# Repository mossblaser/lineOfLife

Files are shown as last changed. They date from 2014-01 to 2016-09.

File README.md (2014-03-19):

Line-of-Life
============

A glow-in-the-dark display for 1D cellular automata and other fun.

Python Library
--------------

A Python library is included for interfacing with the display. This can be
installed as follows:

	cd python/
	sudo python setup.py install

Example programs using this library are included in `python/examples/`.

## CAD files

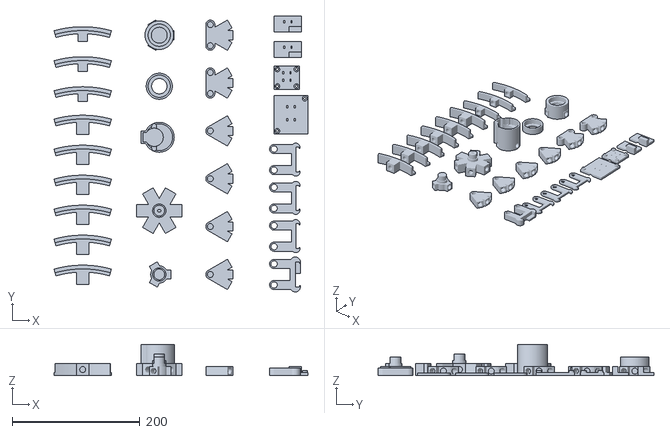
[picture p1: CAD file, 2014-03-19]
physical/all_components.stl
398.1 x 432.4 x 49.2

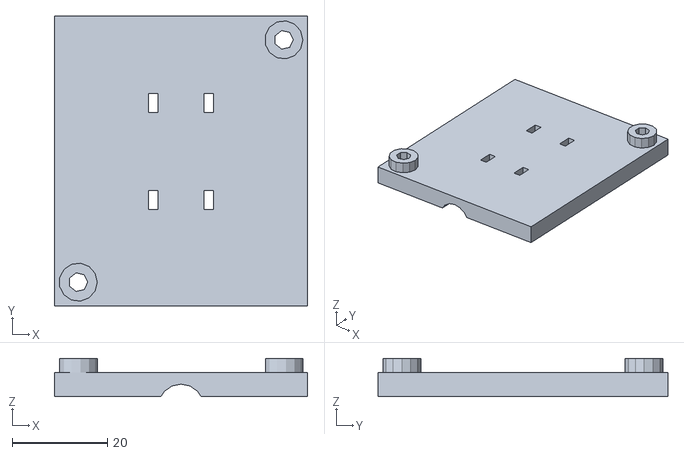
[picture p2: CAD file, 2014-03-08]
physical/arduino_holder.stl
53.1 x 60.8 x 8.00

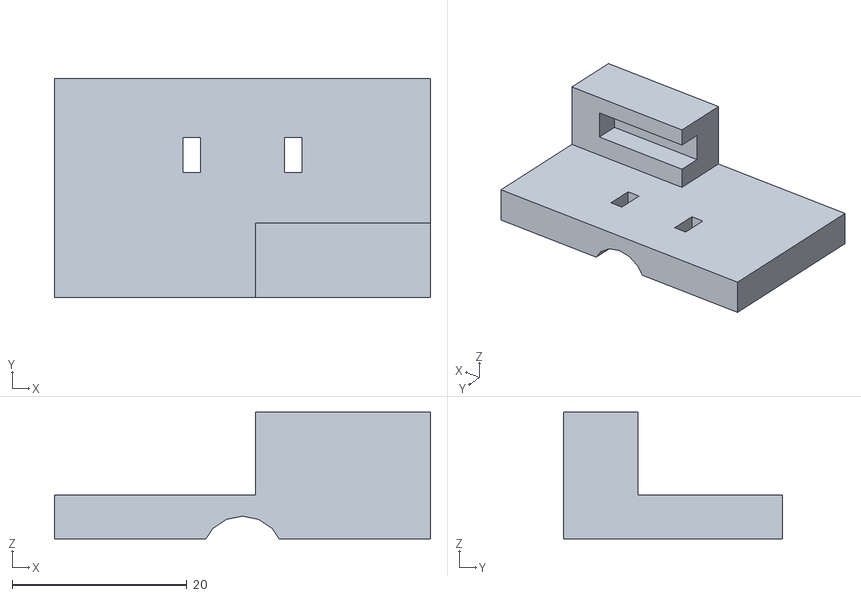
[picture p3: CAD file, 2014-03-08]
physical/junction_board_holder.stl
43.0 x 25.0 x 14.5

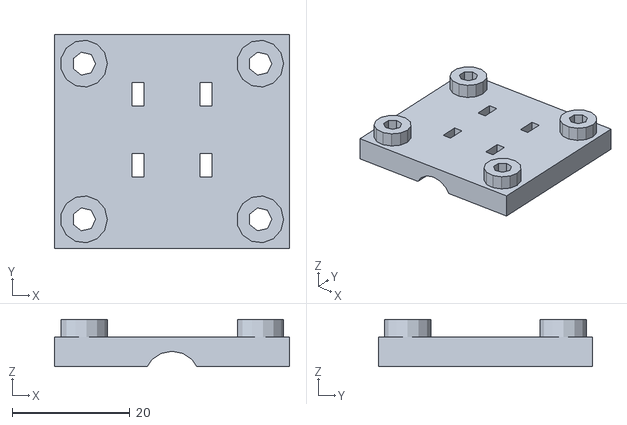
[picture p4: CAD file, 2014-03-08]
physical/motor_driver_holder.stl
40.0 x 36.5 x 8.00

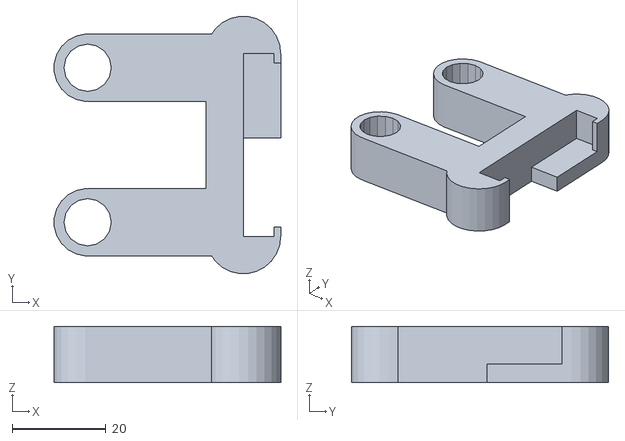
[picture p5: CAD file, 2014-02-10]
physical/led_holder.stl
48.4 x 54.9 x 12.0

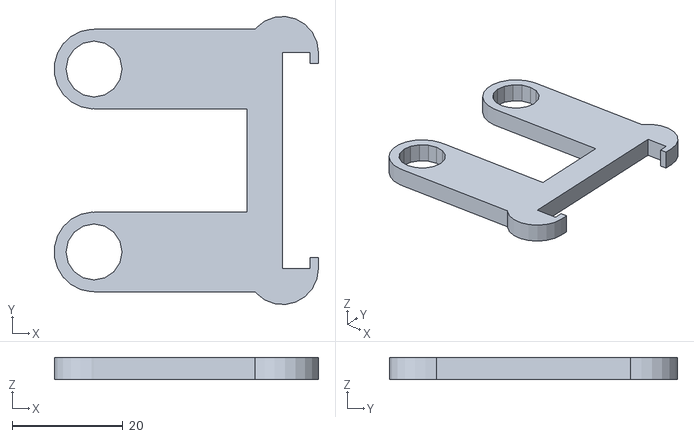
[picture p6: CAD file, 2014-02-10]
physical/led_grip.stl
47.6 x 52.0 x 4.00

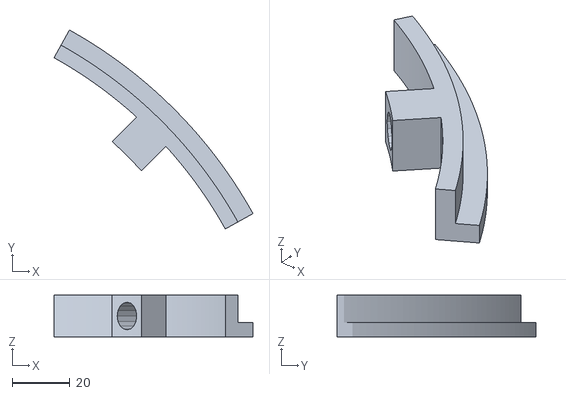
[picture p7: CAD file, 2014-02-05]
physical/top_display_grip.stl
69.0 x 69.0 x 14.4

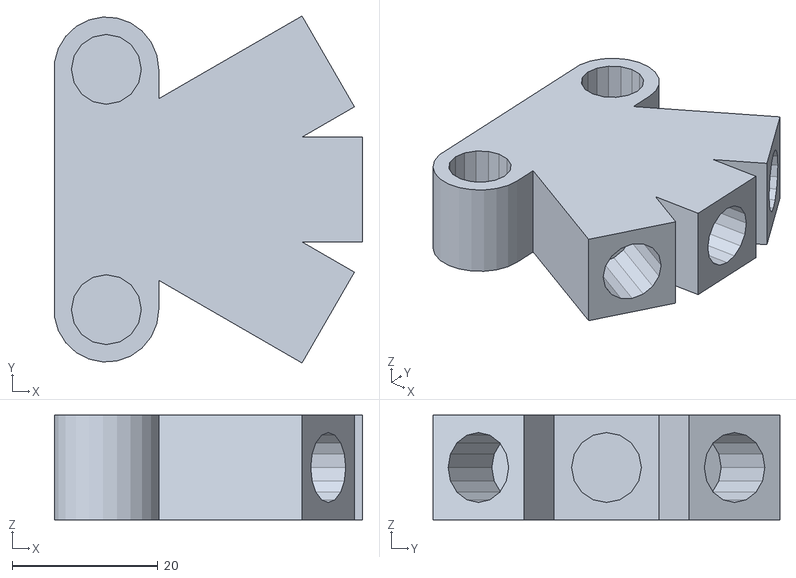
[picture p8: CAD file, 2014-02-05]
physical/double_bracket.stl
42.3 x 47.7 x 14.4

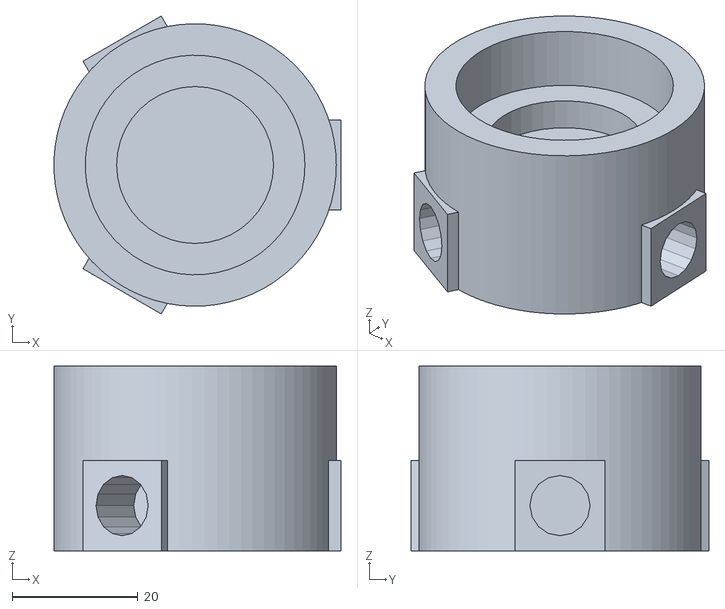
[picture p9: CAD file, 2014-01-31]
physical/top_bearing_grip.stl
45.7 x 47.5 x 29.4

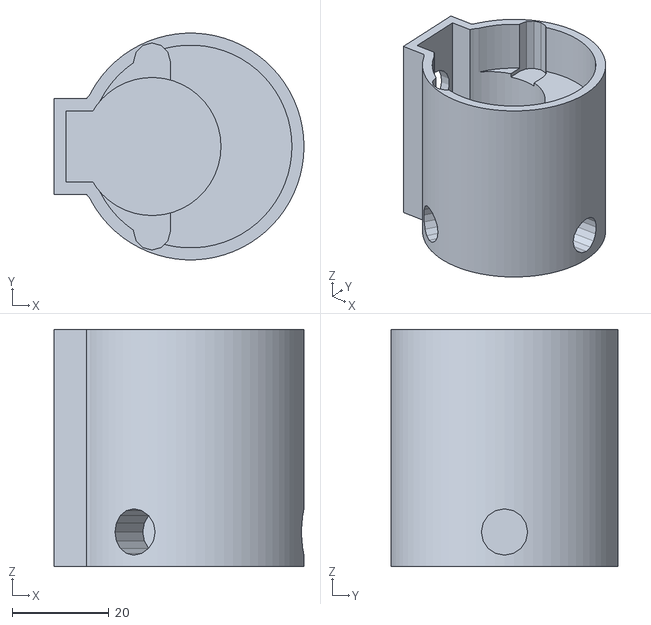
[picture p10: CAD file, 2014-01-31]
physical/motor_base.stl
51.8 x 47.0 x 49.2

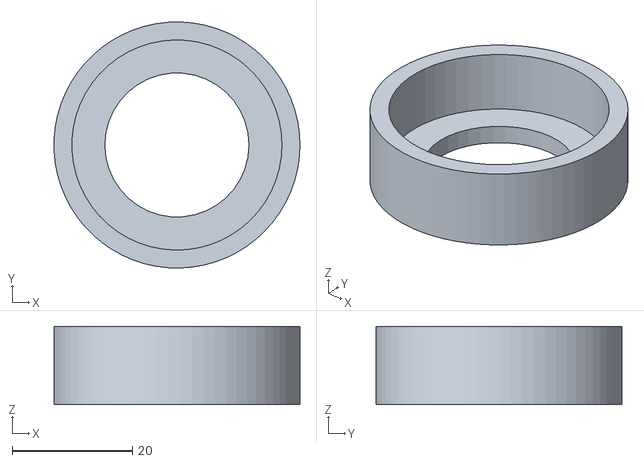
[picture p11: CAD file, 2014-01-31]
physical/motor_base_bearing_fitting.stl
41.0 x 41.0 x 13.0

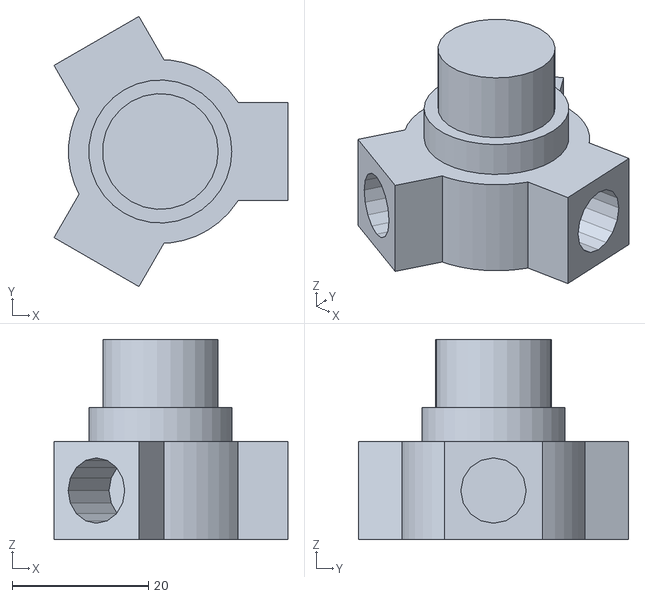
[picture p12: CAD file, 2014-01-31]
physical/top_axel.stl
34.4 x 39.7 x 29.4

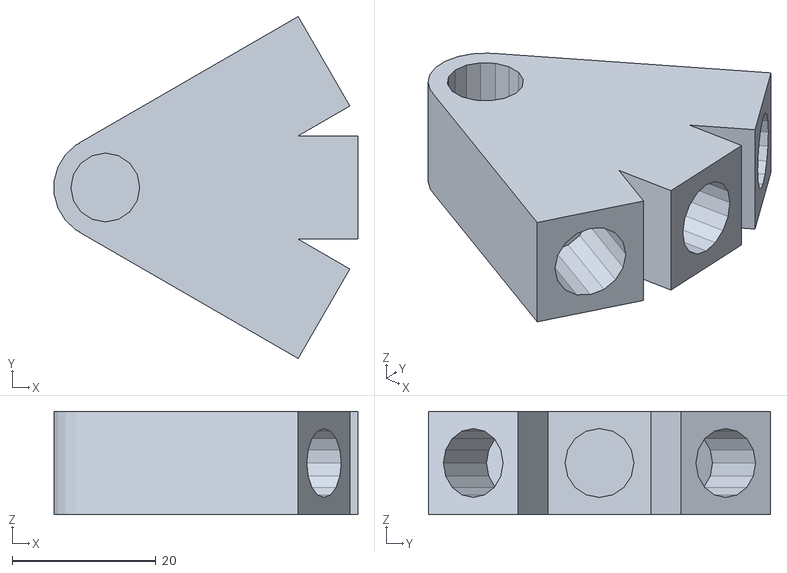
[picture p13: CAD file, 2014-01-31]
physical/bracket.stl
42.3 x 47.7 x 14.4

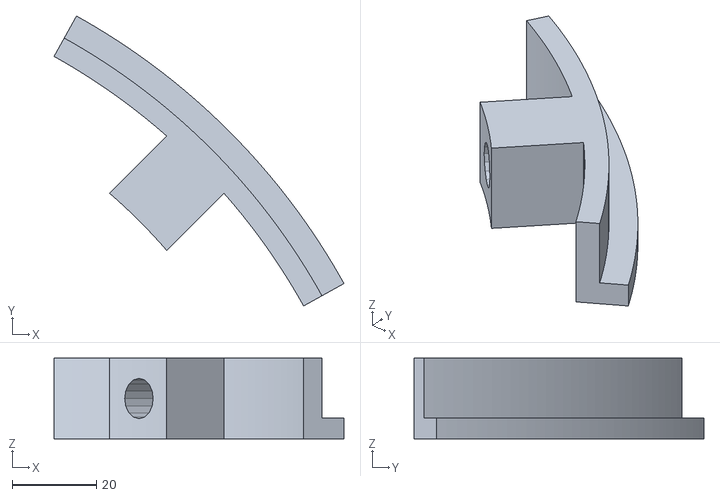
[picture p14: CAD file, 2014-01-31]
physical/base_display_grip.stl
69.0 x 69.0 x 19.2

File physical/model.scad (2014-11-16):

include <wedge.scad>;

// Minimum angle for fragmenting curves
$fa = 1;
//$fs = 0.5;

PI = 3.1415927;

////////////////////////////////////////////////////////////////////////////////
// Size Definitions
////////////////////////////////////////////////////////////////////////////////

// Size of the dowel rods used in construction
DOWEL_DIAMETER = 9;
DOWEL_RADIUS   = DOWEL_DIAMETER/2;

// Sizes of holes for dowel rods in various situations
DOWEL_PRINTED_SOCKET_RADIUS= DOWEL_RADIUS + 0.3;
DOWEL_CUT_HOLE_RADIUS= DOWEL_RADIUS * 3;

// Thickness of a block into which a dowel rod inserted should be
DOWEL_PRINTED_SOCKET_BLOCK = DOWEL_PRINTED_SOCKET_RADIUS * 3;
// Depth of a socket to accept the dowel rod
DOWEL_PRINTED_SOCKET_DEPTH = DOWEL_PRINTED_SOCKET_RADIUS * 2.5;

// As above but for load-bearing joints
DOWEL_PRINTED_SOCKET_BLOCK_LOADED = DOWEL_PRINTED_SOCKET_RADIUS * 4;
DOWEL_PRINTED_SOCKET_DEPTH_LOADED = DOWEL_PRINTED_SOCKET_RADIUS * 4;

// Maximum 3D printable size
MAX_3D_PRINT_DIMENSION = 90;

// Size of the glow-in-the-dark cylinder
DISPLAY_HEIGHT       = 609.6; // 24in
DISPLAY_CIRCUMFRENCE = 1000;  // 1m
DISPLAY_RADIUS       = (DISPLAY_CIRCUMFRENCE / PI) / 2;
DISPLAY_THICKNESS    = 1;


// The cardboard rings which live inside the display to hold its shape
DISPLAY_SHAPE_RING_THICKNESS = 3;  // Cardboard Thickness
DISPLAY_SHAPE_RINGS_START    = 50; // The offset from the bottom of the cylinder of the first ring.
DISPLAY_SHAPE_RINGS_END      = 50; // The offset from the top of the cylinder of the last ring.
DISPLAY_SHAPE_RINGS_NUM      = 3;  // Number of shaping rings

// Size of the ledge on each of the spokes which the display will rest.
DISPLAY_GRIP_LEDGE = 5;
// Thickness of the ledge on which the display sits
DISPLAY_GRIP_THICKNESS = 5;

// Bearing dimensions
BEARING_INNER_RADIUS = 18/2; // Inner radius
BEARING_OUTER_RADIUS = 34/2; // Outer radius
BEARING_THICKNESS    = 10;   // Ring thickness
BEARING_INNER_LIP    = 2;    // Size of the edge of the inner ring
BEARING_OUTER_LIP    = 5;    // Size of the fixed outer ring
BEARING_PRINT_SLACK  = 0.5;  // Amount of slack to add to the radius for 3D printed fittings

// Motor shaft dimensions
MOTOR_SHAFT_RADIUS        = (5+0.5)/2;
MOTOR_SHAFT_KEY_WIDTH     = 3+0.5;
MOTOR_SHAFT_LENGTH        = 6+1;
MOTOR_SHAFT_CENTER_OFFSET = 8;

// Motor Body Dimensions
MOTOR_RADIUS = 28/2 + 0.3;
MOTOR_BLOCK_RADIUS = 17.5 + 0.3;
MOTOR_BLOCK_WIDTH = 14.5 + 0.3;
MOTOR_DEPTH = 19 + 0.3;
MOTOR_TAB_RADIUS = 7/2 + 0.3;
MOTOR_TAB_SPACING = 35 + 0.3;
MOTOR_TAB_THICKNESS = 1;
MOTOR_WIRE_WIDTH = 12;
MOTOR_WIRE_HEIGHT = 15;

// Motor holder wall thicknesses
MOTOR_WALL_THICKNESS = 2.5;
// The thickness of the motor bearing cup's base
MOTOR_SHELF_THICKNESS = 3;
// The thickness of the outer ring around the base bearing
MOTOR_SHELF_RING_THICKNESS = 4;
// Slack added to the shelf's dimensions itself 
MOTOR_SHELF_SLACK = 0.5;

// Number of spokes/grips used to support the display
DISPLAY_BASE_SPOKES = 6;
// Number of spokes at the top of the display
DISPLAY_TOP_SPOKES = 3;

// Seperation between the two rods which run down the side of the system
// attached to the electronics.
DOUBLE_SHAFT_SEP = 33; // Approximately the width of circuit board (1.4")


// Parameters for the LED board holder
LED_GRIP_THICKNESS   = 4;
LED_HOLDER_THICKNESS = DOWEL_PRINTED_SOCKET_BLOCK;
LED_ARM_THICKNESS = 2.5; // Thickness of the fingers at the end of the arm
LED_ARM_OVERHANG = 2;//

// Distance of the LED boards from the dowel rod centers
LED_DISTANCE = 36;

LED_BOARD_THICKNESS = 4.0;
LED_WIDE_BOARD_THICKNESS = 5.5;
LED_SUPPORT_WIDTH = 18;
LED_BOARD_WIDTH = 39;

// Thickness of the panels holding circuit boards
CIRCUIT_HOLDER_THICKNESS = 5;

// Size of cable-ties
CABLE_TIE_THICKNESS = 2.0;
CABLE_TIE_WIDTH = 4.0;

// Screws and standoffs
SCREW_RADIUS = 2;
STANDOFF_RADIUS = 4;
STANDOFF_HEIGHT = 3;

// Clamp thickness for board holders
CLAMP_THICKNESS = 2.5;


////////////////////////////////////////////////////////////////////////////////
// Colour Palette
////////////////////////////////////////////////////////////////////////////////

COLOUR_CARDBOARD    = [184/255,165/255,103/255];
COLOUR_GLOW_IN_DARK = [198/255,245/255,188/255];
COLOUR_3D_PRINTED   = [0.2,0.2,0.2];


////////////////////////////////////////////////////////////////////////////////
// Components
////////////////////////////////////////////////////////////////////////////////

// The display cylinder and axel
module display() {
	// The display surface itself
	%color(COLOUR_GLOW_IN_DARK)
		difference() {
			cylinder(h = DISPLAY_HEIGHT, r=DISPLAY_RADIUS);
			translate([0,0,-0.5])
			cylinder(h = DISPLAY_HEIGHT+1, r=DISPLAY_RADIUS - DISPLAY_THICKNESS);
		}
	
	// The cardboard support rings 
	color(COLOUR_CARDBOARD)
		for (i = [0 : DISPLAY_SHAPE_RINGS_NUM-1]) {
			translate([0,0,DISPLAY_SHAPE_RINGS_START
			                 + i * (( DISPLAY_HEIGHT
			                          - DISPLAY_SHAPE_RINGS_START
			                          - DISPLAY_SHAPE_RINGS_END
			                        ) / (DISPLAY_SHAPE_RINGS_NUM-1))
			          ])
				difference() {
					// The ring
					cylinder( h = DISPLAY_SHAPE_RING_THICKNESS
					        , r = DISPLAY_RADIUS - DISPLAY_THICKNESS
					        );
					// Space for the axel
					translate([0,0,-0.5])
					cylinder( h = DISPLAY_SHAPE_RING_THICKNESS+1
					        , r = DOWEL_CUT_HOLE_RADIUS
					        );
				}
		}
}


// A part which sits on the end of a spoke and grips the display
module display_grip( angle
                   , DOWEL_PRINTED_SOCKET_BLOCK = DOWEL_PRINTED_SOCKET_BLOCK
                   , DOWEL_PRINTED_SOCKET_DEPTH = DOWEL_PRINTED_SOCKET_DEPTH
                   ) {
	// A wedge the width of the ledge which should be as big as can be 3D
	// printed (cosine rule)
	wedge_angle = acos( (2*pow(DISPLAY_RADIUS+DISPLAY_GRIP_LEDGE,2) - pow(MAX_3D_PRINT_DIMENSION,2))
	                    / (2*pow(DISPLAY_RADIUS+DISPLAY_GRIP_LEDGE,2))
	                  );
	
	echo("Difference of axel radius from display radius: ", DISPLAY_THICKNESS + DISPLAY_GRIP_THICKNESS);
	
	color(COLOUR_3D_PRINTED)
	rotate([0,0, angle]) {
		difference() {
			// The wedge with a lip
			intersection() {
				// The profile of the ledge
				union() {
					// The spoke accepting part
					cylinder( h = DOWEL_PRINTED_SOCKET_BLOCK
					        , r = DISPLAY_RADIUS - DISPLAY_THICKNESS
					        );
					// The ledge
					cylinder( h = DISPLAY_GRIP_THICKNESS
					        , r = DISPLAY_RADIUS + DISPLAY_GRIP_LEDGE
					        );
				}
				rotate([0,0, -wedge_angle/2])
					wedge( h = DOWEL_PRINTED_SOCKET_BLOCK
					     , r = DISPLAY_RADIUS + DISPLAY_GRIP_LEDGE
					     , d = wedge_angle
					     );
			}
			
			// The excess wedge excluding space for the axel
			difference() {
				translate([0,0,-0.5])
				cylinder( h = DOWEL_PRINTED_SOCKET_BLOCK + 1
				        , r = DISPLAY_RADIUS - DISPLAY_THICKNESS - DISPLAY_GRIP_THICKNESS
				        );
				translate([0, -DOWEL_PRINTED_SOCKET_BLOCK/2, 0])
					cube([ DISPLAY_RADIUS - DISPLAY_THICKNESS
					     , DOWEL_PRINTED_SOCKET_BLOCK
					     , DOWEL_PRINTED_SOCKET_BLOCK
					     ]);
			}
			
			// The excess axel socket 
			translate([0,0,-0.5])
			cylinder( h = DOWEL_PRINTED_SOCKET_BLOCK + 1
			        , r = DISPLAY_RADIUS
			              - DISPLAY_THICKNESS
			              - DISPLAY_GRIP_THICKNESS
			              - DOWEL_PRINTED_SOCKET_DEPTH
			        );
			
			// Drill out the hole for the dowel
			translate([0, 0, DOWEL_PRINTED_SOCKET_BLOCK/2])
				rotate([0, 90, 0])
					cylinder( h = DISPLAY_RADIUS - DISPLAY_THICKNESS - DISPLAY_GRIP_THICKNESS
					        , r = DOWEL_PRINTED_SOCKET_RADIUS
					        );
		}
	}
}
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

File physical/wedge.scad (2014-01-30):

//Title: Wedge Module
//Author: Alex English - ProtoParadigm
//Date: 1/4/2013
//License: Creative Commons - Share Alike - Attribution

//Usage: Include in your other .scad projects and call wedge with arguments for the height of the wedge, the radius of the wedge, and the angle of the wedge in degrees.  The resulting wedge will be placed with the point at the origin, extending into the z axis, with the angle starting at the x axis and extending counter-clockwise as per the right-hand rule.

//Updated: 1/12/2013 - Increased dimensions of wedge to be revoved when angle is more than 180 as per suggestion from kitwallace.

module wedge_180(h, r, d)
{
	rotate(d) difference()
	{
		rotate(180-d) difference()
		{
			cylinder(h = h, r = r);
			translate([-(r+1), 0, -1]) cube([r*2+2, r+1, h+2]);
		}
		translate([-(r+1), 0, -1]) cube([r*2+2, r+1, h+2]);
	}
}

module wedge(h, r, d)
{
	if(d <= 180)
		wedge_180(h, r, d);
	else
		rotate(d) difference()
		{
			cylinder(h = h, r = r);
			translate([0, 0, -1]) wedge_180(h+2, r+1, 360-d);
		}
}

//Example: wedge(10, 20, 145); //would create a wedge 10 high, with a radius of 20, and an angle of 33 degrees.

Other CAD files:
physical/base_axel.stl

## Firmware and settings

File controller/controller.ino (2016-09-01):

/**
 * Controller for the Line of Life display.
 */

#include <limits.h>

#include <SPI.h>

#include "TimerOne.h"

#include "controller.h"


////////////////////////////////////////////////////////////////////////////////
// Stepper Motor Driver
////////////////////////////////////////////////////////////////////////////////

// Accumulated number of steps taken.
static volatile unsigned char num_steps;

// Current stepper motor state
static int cur_motor_state = 0;


static void
on_timer_interrupt(void)
{
	// Step the motor
	if (STEPPER_CLOCKWISE) {
		for (int i = 0; i < 4; i++)
			digitalWrite(MOTOR_PINS[4-i-1], (MOTOR_STATES[cur_motor_state] & 1<<i)!=0);
	} else {
		for (int i = 0; i < 4; i++)
			digitalWrite(MOTOR_PINS[i], (MOTOR_STATES[cur_motor_state] & 1<<i)!=0);
	}
	
	num_steps++;
	
	// Advance stepper state
	cur_motor_state ++;
	if (cur_motor_state >= NUM_MOTOR_STATES)
		cur_motor_state = 0;
}


void
motor_setup(void)
{
	// Set up pins
	for (int i = 0; i < 4; i++) {
		pinMode(MOTOR_PINS[i], OUTPUT);
		digitalWrite(MOTOR_PINS[i], LOW);
	}
	
	Timer1.initialize(STEP_MICROSECONDS);
	Timer1.attachInterrupt(on_timer_interrupt);
}

////////////////////////////////////////////////////////////////////////////////
// Automata rendering (for when the host is not sending anything...)
////////////////////////////////////////////////////////////////////////////////

#ifdef SHOW_AUTOMATA

// The bitmap of the text to display before showing each rule is displayed
static unsigned char presenting_msg[][NUM_VERTICAL_BYTES] = {
#include "presenting_bitmap.h"
};
#define PRESENTING_MSG_LENGTH (sizeof(presenting_msg) / sizeof(unsigned char[NUM_VERTICAL_BYTES]))

// The bitmaps of the numbers
static unsigned char numbers[10][PRESENTING_MSG_LENGTH] = {
#include "number_bitmaps.h"
};

typedef enum {
	// Pick a rule to demonstrate and output a blank line to seperate off the
	// previous image.
	AUTOMATA_MODE_PICK_RULE,
	
	// Output some text stating which rule is about to be shown
	AUTOMATA_MODE_TEXT,
	
	// Generate and display an initial state for the automaton
	AUTOMATA_MODE_INITIAL_STATE,
	
	// Run the cellular automaton and output the current state (for a while).
	AUTOMATA_MODE_RUN,
} automata_mode_t;

/**
 * Returns a pointer to a line of display graphics to show which (over time)
 * illustrates the operation of a 1D cellular automata. Call once per line.
 */
unsigned char *get_automata_frame() {
	static automata_mode_t mode = AUTOMATA_MODE_PICK_RULE;
	
	// The current rule to use
	static int rule = 0;
	
	// The current frame number for this automaton
	static int frame = AUTOMATA_FRAMES;
	
	// Buffers holding the current state and a second buffer to write the new
	// state into. Flipped after each update. Though in principle only one buffer
	// is needed, having two a: simplifies life a little but mostly b: means we
	// can check if the automata actually does anything!
	static unsigned char buf_a[NUM_VERTICAL_BYTES] = {1};
	static unsigned char buf_b[NUM_VERTICAL_BYTES] = {1};
	static unsigned char *cur_state = buf_a;
	static unsigned char *next_state = buf_b;
	
	switch (mode) {
		
		case AUTOMATA_MODE_PICK_RULE:
			// Pick a new rule. With a 75% chance, pick a known good one
			if (random(4) == 0) {
				rule = random(0x00, 0xFF + 1);
			} else {
				int good_rules[] = AUTOMATA_KNOWN_GOOD_RULES;
				rule = good_rules[random(sizeof(good_rules) / sizeof(good_rules[0]))];
			}
			
			mode = AUTOMATA_MODE_TEXT;
			frame = 0;
			
			// Display a blank line
			for (int byte_num = 0; byte_num < NUM_VERTICAL_BYTES; byte_num++)
				cur_state[byte_num] = 0;
			return cur_state;
		
		case AUTOMATA_MODE_TEXT:
			// The fixed text
			for (int byte_num = 0; byte_num < NUM_VERTICAL_BYTES; byte_num++)
				cur_state[byte_num] = presenting_msg[frame][byte_num];
			
			// Add the rule number to the text
			{
				int offset = NUM_VERTICAL_BYTES - 3;
				int hundreds = rule / 100;
				int tens = (rule - (hundreds * 100)) / 10;
				int units = rule - (hundreds * 100) - (tens * 10);
				if (hundreds)
					cur_state[offset++] = numbers[hundreds][frame];
				if (hundreds || tens)
					cur_state[offset++] = numbers[tens][frame];
				cur_state[offset++] = numbers[units][frame];
			}
			
			frame++;
			if (frame >= PRESENTING_MSG_LENGTH) {
				mode = AUTOMATA_MODE_INITIAL_STATE;
				frame = 0;
			}
			
			return cur_state;
		
		case AUTOMATA_MODE_INITIAL_STATE:
			// Chose a starting state (either random or a single pixel)
			if (random(2) == 0) {
				// Random
				for (int byte_num = 0; byte_num < NUM_VERTICAL_BYTES; byte_num++)
					cur_state[byte_num] = random(0x00, 0xFF + 1);
			} else {
				// Single pixel
				for (int byte_num = 0; byte_num < NUM_VERTICAL_BYTES; byte_num++)
					cur_state[byte_num] = 0;
				cur_state[NUM_VERTICAL_BYTES / 2] = 1<<4;
			}
			
			mode = AUTOMATA_MODE_RUN;
			frame = 0;
			
			return cur_state;
		
		case AUTOMATA_MODE_RUN:
			// Compute next automata state
			for (int bit_num = 0; bit_num < VERTICAL_PIXELS; bit_num++) {
				int cur_byte_num =  bit_num / 8;
				int cur_bit_index = bit_num % 8;
				int prev_byte_num =  (bit_num-1) / 8;
				int prev_bit_index = (bit_num-1) % 8;
				int next_byte_num =  (bit_num+1) / 8;
				int next_bit_index = (bit_num+1) % 8;
				
				unsigned char cur_byte = cur_state[cur_byte_num];
				unsigned char prev_byte = (prev_byte_num >= 0 &&
				                           prev_byte_num < NUM_VERTICAL_BYTES)
				                          ? cur_state[prev_byte_num]
				                          : 0;
				unsigned char next_byte = (next_byte_num >= 0 &&
				                           next_byte_num < NUM_VERTICAL_BYTES)
				                          ? cur_state[next_byte_num]
				                          : 0;
				
				bool cur_bit = (cur_byte >> cur_bit_index) & 1;
				bool prev_bit = (prev_byte >> prev_bit_index) & 1;
				bool next_bit = (next_byte >> next_bit_index) & 1;
				
				next_state[cur_byte_num] = (next_state[cur_byte_num] & ~(1<<cur_bit_index))
				                           | (((rule >> ((prev_bit << 0) +
				                                         (cur_bit  << 1) +
				                                         (next_bit << 2))) & 1) << cur_bit_index);
			}
			
			// Flip the two buffers
			{
				unsigned char *tmp = cur_state;
				cur_state = next_state;
				next_state = tmp;
			}
			
			// If the state hasn't meaningfully changed or we've run for long enough,
			// move on to the next state
			{
				frame++;
				
				bool changed = false;
				for (int byte_num = 0; byte_num < NUM_VERTICAL_BYTES; byte_num++)
					changed |= cur_state[byte_num] != next_state[byte_num];
				
				if ((frame > AUTOMATA_MIN_FRAMES && !changed) ||
				    frame >= AUTOMATA_FRAMES)
					mode = AUTOMATA_MODE_PICK_RULE;
			}
			
			return cur_state;
		
		default:
			mode = AUTOMATA_MODE_PICK_RULE;
			return cur_state;
	}
}

#endif

////////////////////////////////////////////////////////////////////////////////
// LED Driving
////////////////////////////////////////////////////////////////////////////////

// Display buffer (head==tail is empty)
unsigned char buf[DISPLAY_BUFFER_LENGTH][NUM_VERTICAL_BYTES];
unsigned int  buf_head=0u;
unsigned int  buf_tail=0u;

// Emergency buffer -- a bitmap to display if no pixels are sent
#ifndef SHOW_AUTOMATA
static unsigned char emg_buf[][NUM_VERTICAL_BYTES] = {
#include "error_bitmap.h"
};
#define EMG_BUF_LENGTH (sizeof(emg_buf) / sizeof(unsigned char[NUM_VERTICAL_BYTES]))
static unsigned int emg_buf_cursor = 0u;
#endif


// Current pixel width, in pixel fractions (default to square pixels)
unsigned int cur_pixel_width = PIXEL_FRACTION;
unsigned int next_pixel_width = PIXEL_FRACTION;

// The amount of the cur_pixel_width (in pixel fractions) the LEDs are on.
unsigned int cur_pixel_duty = PIXEL_FRACTION;
unsigned int next_pixel_duty = PIXEL_FRACTION;


/**
 * Immediately empty the LED line buffer
 */
void
led_buffer_clear()
{
	buf_head = buf_tail = 0;
}


/**
 * Find out if the LED output buffer is empty
 */
bool
is_led_buffer_empty()
{
	return buf_head == buf_tail;
}


/**
 * Set the width of the next pixel to be displayed.
 */
void
led_set_pixel_width(unsigned int pixel_width)
{
	unsigned int old_pixel_width = next_pixel_width;
	
	next_pixel_width = pixel_width;
	// Clamp value 
	if (next_pixel_width <= 0)
		next_pixel_width = 1u;
	
	// Scale the duty to match the new pixel width
	led_set_pixel_duty((next_pixel_width*led_get_pixel_duty()) / old_pixel_width);
}


/**
 * Get the width of the next pixel to be displayed.
 */
unsigned int
led_get_pixel_width(void)
{
	return next_pixel_width;
}


/**
 * Set the duty of the next pixel to be displayed.
 */
void
led_set_pixel_duty(unsigned int pixel_duty)
{
	next_pixel_duty = pixel_duty;
	// Clamp value
	if (next_pixel_duty <= 0)
		next_pixel_duty = 1u;
	else if (next_pixel_duty > led_get_pixel_width())
		next_pixel_duty = led_get_pixel_width();
}


/**
 * Get the duty of the next pixel to be displayed.
 */
unsigned int
led_get_pixel_duty(void)
{
	return next_pixel_duty;
}


/**
 * Insert an item into the buffer. Returns a pointer to the buffer entry which
 * has been allocated or NULL if the buffer is full.
 */
unsigned char *
led_buffer_insert(void)
{
	unsigned int old_tail = buf_tail;
	unsigned int new_tail = (old_tail+1)%DISPLAY_BUFFER_LENGTH;
	if (new_tail == buf_head) {
		// The buffer is full
		return NULL;
	} else {
		buf_tail = new_tail;
		return buf[old_tail];
	}
}


/**
 * Number of free spaces in the buffer.
 */
unsigned int
get_led_buffer_spaces()
{
	return (((int)buf_head - (int)buf_tail) + (int)DISPLAY_BUFFER_LENGTH - 1) % (int)DISPLAY_BUFFER_LENGTH;
}

/**
 * Refresh the LED display if needed
 */
void
led_loop() {
	// Control the duty-cycle of the display
	digitalWrite(nOE_PIN, !(num_steps < STEPS_PER_PIXEL_FRACTION(cur_pixel_duty)));
	
	// Does the display actually need to be refreshed?
	if (num_steps < STEPS_PER_PIXEL_FRACTION(cur_pixel_width))
		return;
	
	// Only maintain the period if the pixel width hasn't changed
	if (cur_pixel_width != next_pixel_width)
		num_steps = 0;
	else
		num_steps %= STEPS_PER_PIXEL_FRACTION(cur_pixel_width);
	
	// Update the pixel duty and width
	cur_pixel_width = next_pixel_width;
	cur_pixel_duty  = next_pixel_duty;
	
	// Work out what to display
	unsigned char *cur_buf;
	if (buf_head == buf_tail) {
#ifdef SHOW_AUTOMATA
		// Empty buffer, run the automata demo
		cur_buf = get_automata_frame();
#else
		// Empty buffer, show 'emergency' message
		cur_buf = &(emg_buf[emg_buf_cursor++][0]);
		if (emg_buf_cursor >= EMG_BUF_LENGTH)
			emg_buf_cursor = 0u;
#endif
	} else {
		// Consume item from buffer
		cur_buf = &(buf[buf_head++][0]);
		if (buf_head >= DISPLAY_BUFFER_LENGTH)
			buf_head = 0u;
		
		// Also reset the emergency buffer cursor so the emergency buffer starts
		// from scratch when it is next used.
		emg_buf_cursor = 0u;
	}
	
	// Refresh the display
	for (int i = NUM_VERTICAL_BYTES-1; i>=0; i--)
		SPI.transfer(cur_buf[i]);
	digitalWrite(LE_PIN, HIGH);
	digitalWrite(LE_PIN, LOW);
	
}


////////////////////////////////////////////////////////////////////////////////
// Command Interface
////////////////////////////////////////////////////////////////////////////////


/**
 * Command interface state-machine states.
 */
enum cmd_state {
	// The normal state while not running any particular command.
	CMD_STATE_IDLE,
	
	// Reading in a line of display values from the host
	CMD_STATE_READ_LINE,
	
	// Waiting for the display buffer to become non-full before confirming to the
	// host that this has occurred.
	CMD_STATE_WAIT_UNTIL_BUFFER_NOT_FULL,
	
	// Waiting for the display buffer to become flushed.
	CMD_STATE_FLUSH,
	
	// Waiting for a register's write data to arrive
	CMD_STATE_READ_REG_VALUE,
} cmd_state = CMD_STATE_IDLE;


/**
 * The register which will be written in the CMD_STATE_READ_REG_VALUE state.
 */
reg_t selected_register;


unsigned int
cmd_read_reg(reg_t reg)
{
	switch (reg) {
		case REG_DISPLAY_HEIGHT: return VERTICAL_PIXELS;           break;
		case REG_DISPLAY_WIDTH:  return HORIZONTAL_PIXELS;         break;
		case REG_RPM:            return (int)(DISPLAY_RPM*(1<<8)); break;
		
		case REG_PIXEL_ASPECT_RATIO:
			// Convert to fixed point 8.8
			return (led_get_pixel_width()<<8) / PIXEL_FRACTION;
		
		case REG_PIXEL_DUTY:
			// Convert to fixed point 8.8
			return (led_get_pixel_duty()<<8) / led_get_pixel_width();
		
		case REG_BUFFER_SIZE:
			return (DISPLAY_BUFFER_LENGTH-1)<<16 | get_led_buffer_spaces();
		
		default:
			// Return 0xDEAD for nonexistant registers
			return 0xDEADu;
	}
}

void
cmd_write_reg(reg_t reg, unsigned int value)
{
	switch (reg) {
		// Read-only registers
		default:
		case REG_DISPLAY_HEIGHT:
		case REG_DISPLAY_WIDTH:
		case REG_RPM:
		case REG_BUFFER_SIZE:
			break;
		
		case REG_PIXEL_ASPECT_RATIO:
			// Convert from fixed point 8.8
			led_set_pixel_width((PIXEL_FRACTION * value)>>8);
			break;
		
		case REG_PIXEL_DUTY:
			// Find number of pixel fractions in 8.8 and then convert to integer.
			led_set_pixel_duty((value * led_get_pixel_width())>>8);
			break;
	}
}


/**
 * Execute one iteration of the command evaluating state machine. This should be
 * interleaved with the LED driving state machine for propper operation.
 */
void
cmd_loop(void)
{
	switch (cmd_state) {
		case CMD_STATE_IDLE:
			// Try and read a command
			if (Serial.available()) {
				unsigned char cmd      = Serial.read();
				opcode_t opcode        = (opcode_t)(cmd & CMD_OPCODE_MASK);
				unsigned int immediate = cmd & CMD_IMMEDIATE_MASK;
				
				switch (opcode) {
					// Unrecognised commands are ignored
					default:
					case OPCODE_NO_OPERATION:
						return;
					
					case OPCODE_PUSH_LINE:
						cmd_state = CMD_STATE_READ_LINE;
						break;
					
					case OPCODE_FLUSH_BUFFER:
						cmd_state = CMD_STATE_FLUSH;
						break;
					
					case OPCODE_CLEAR_BUFFER:
						led_buffer_clear();
						break;
					
					case OPCODE_REG_READ:
						{
							unsigned int reg_value = cmd_read_reg((reg_t)immediate);
							Serial.write((unsigned char)(reg_value>>8u));
							Serial.write((unsigned char)(reg_value&0xFFu));
						}
						break;
					
					case OPCODE_REG_WRITE:
						cmd_state = CMD_STATE_READ_REG_VALUE;
						selected_register = (reg_t)immediate;
						break;
					
					case OPCODE_PING:
						Serial.write((unsigned char)(PROTOCOL_VERSION<<4u | ((unsigned char)immediate)));
						break;
				}
			}
			break;
		
		case CMD_STATE_READ_LINE:
			// Wait for a full line of input to arrive for the display
			if (Serial.available() >= NUM_VERTICAL_BYTES) {
				// Place the pixels in the buffer
				unsigned char *buffer = led_buffer_insert();
				if (buffer == NULL) {
					// Discard the data, for some reason we tried to over-fill the buffer
					for (int i = 0; i < NUM_VERTICAL_BYTES; i++)
						Serial.read();
				} else {
					for (int i = 0; i < NUM_VERTICAL_BYTES; i++)
						buffer[i] = Serial.read();
				}
				// Potentially block until the buffer has more space
				cmd_state = CMD_STATE_WAIT_UNTIL_BUFFER_NOT_FULL;
			}
			break;
		
		case CMD_STATE_WAIT_UNTIL_BUFFER_NOT_FULL:
			{
				// Allow the host to un-block the system by sending another command
				if (Serial.available()) {
					cmd_state = CMD_STATE_IDLE;
					break;
				}
				
				// Block until there are free spaces in the output buffer
				unsigned int free_spaces = get_led_buffer_spaces();
				if (free_spaces) {
					Serial.write(free_spaces);
					cmd_state = CMD_STATE_IDLE;
				}
			}
			break;
		
		case CMD_STATE_FLUSH:
			// Allow the host to un-block the system by sending another command
			if (Serial.available()) {
				cmd_state = CMD_STATE_IDLE;
				break;
			}
			
			// Block until the buffer is empty
			if (is_led_buffer_empty()) {
				Serial.write(0xFF);
				cmd_state = CMD_STATE_IDLE;
			}
			break;
		
		case CMD_STATE_READ_REG_VALUE:
			if (Serial.available() >= 2) {
				// Read the new value
				unsigned int value = Serial.read();
				value = (value<<8u) | Serial.read();
				
				// Write to the register
				cmd_write_reg(selected_register, value);
				cmd_state = CMD_STATE_IDLE;
			}
			break;
		
		default:
			cmd_state = CMD_STATE_IDLE;
	}
}


////////////////////////////////////////////////////////////////////////////////
// Main program
////////////////////////////////////////////////////////////////////////////////


void setup() {
	randomSeed(analogRead(5));
	
	Serial.begin(BAUD_RATE);
	
	SPI.begin();
	SPI.setBitOrder(MSBFIRST);
	SPI.setClockDivider(SPI_CLOCK_DIV16); // 16MHz/16 = 1MHz
	SPI.setDataMode(SPI_MODE0); // Posedge sensitive, Clock Idle Low
	
	motor_setup();
	
	pinMode(LE_PIN, OUTPUT);
	pinMode(nOE_PIN, OUTPUT);
	
	digitalWrite(LE_PIN, LOW);
	digitalWrite(nOE_PIN, LOW);
}


void loop() {
	led_loop();
	cmd_loop();
}

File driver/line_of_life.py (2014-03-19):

#!/usr/bin/env python

"""
An implementation of and library for the host interface to the Line of Life
controller.
"""

import random


class ProtocolError(Exception):
	"""
	Errors thrown by violations of the LineOfLife protocol.
	"""
	pass


class LineOfLife(object):
	"""
	A (blocking) interface to the Line of LIfe display hardware.
	"""
	
	
	def __init__(self, pipe):
		"""
		Connect to a line of life display at the end of the given pipe, for example
		a Serial connection.
		"""
		
		self.pipe = pipe
		
		# Cached display constants
		self._display_height = None
		self._display_width = None
		
		# Re-sync on first connection
		self.resync()
	
	
	def resync(self):
		"""
		Resynchronise with the controller putting it into the idle state.
		"""
		# Since all blocking commands are terminated by sending a command and no
		# command accepts an infinite number of arguments sending a long stream of
		# NOPs will guarantee the device will end up in the command-accepting state.
		
		for _ in range(100):
			self._cmd_no_operation()
		
		# Ignore any incoming unconsumed bytes
		if hasattr(self.pipe, "flushInput"):
			self.pipe.flushInput()
		
		self._cmd_ping()
	
	
	def push_line(self, line):
		"""
		Push a line of pixels to the display. The pixel values should be given as a
		list of pixel values of length self.display_height. This method blocks when
		the device's on-board buffer is full.
		"""
		assert len(line) == self.display_height \
		     , "Display line must match display height."
		
		line_str = ""
		for byte_offset in range(0, self.display_height, 8):
			byte = 0
			for bit_num in range(7,-1,-1):
				byte <<= 1
				byte |= int(bool(line[byte_offset + bit_num]))
			line_str += chr(byte)
		
		self._cmd_push_line(line_str)
	
	def flush_buffer(self):
		"""
		Block until the device's buffer is empty. Returns as soon as the last item
		from the buffer is sent to the display.
		
		This should be used before changing device settings such as the pixel aspect
		ratio and duty to ensure only subsequent added lines are effected.
		"""
		# Simply a thin wrapper around the native command
		self._cmd_flush_buffer()
	
	
	def clear_buffer(self):
		"""
		Forcibly empty the device's display buffer. The pixel currently displayed
		will not be interrupted.
		"""
		# Simply a thin wrapper around the native command
		self._cmd_clear_buffer()
	
	
	################################################################################
	# Device settings/information
	################################################################################
	
	@property
	def display_height(self):
		"""
		Read only. Get the display height in pixels (also the number of LEDs).
		
		Internally caches this value the first time it is read.
		"""
		if self._display_height is None:
			self._display_height = self._cmd_reg_read(self.REG_DISPLAY_HEIGHT)
		
		return self._display_height
	
	
	@property
	def display_width(self):
		"""
		Read only. Get the display width in pixels (the number of pixels in one
		complete rotation with a pixel aspect ratio of 1:1.
		
		Internally caches this value the first time it is read.
		"""
		if self._display_width is None:
			self._display_width = self._cmd_reg_read(self.REG_DISPLAY_WIDTH)
		
		return self._display_width
	
	
	@property
	def rpm(self):
		"""
		Read only. The display rotation speed in RPM.
		"""
		raw_rpm = self._cmd_reg_read(self.REG_RPM)
		
		# Sign extend
		raw_rpm |= -1<<16 if raw_rpm&0x8000 else 0
		
		# Convert from fixed point to floating point
		return float(raw_rpm) / float(1<<8)
	
	
	@property
	def pixel_aspect_ratio(self):
		"""
		The size of the pixel width as a proportion of a pixel's height.
		"""
		raw_aspect_ratio = self._cmd_reg_read(self.REG_PIXEL_ASPECT_RATIO)
		
		# Convert to a floating point number
		return float(raw_aspect_ratio) / float(1<<8)
	
	
	@pixel_aspect_ratio.setter
	def pixel_aspect_ratio(self, aspect_ratio):
		"""
		The size of the pixel width as a proportion of a pixel's height.
		"""
		assert aspect_ratio > 0.0 \
		     , "Cannot have negative or zero aspect ratio."
		
		# Convert to fixed point
		raw_aspect_ratio = int(aspect_ratio*(1<<8))
		
		# Truncate (as required) and write back
		self._cmd_reg_write(self.REG_PIXEL_ASPECT_RATIO, raw_aspect_ratio & 0xFFFF)
	
	
	@property
	def pixel_duty(self):
		"""
		The proportion of the time pixels are lit during their time for display. Can
		be used to add clean divisions between pixels.
		"""
		raw_duty = self._cmd_reg_read(self.REG_PIXEL_DUTY)
		
		# Convert to a floating point number
		return float(raw_duty) / float(1<<8)
	
	
	@pixel_duty.setter
	def pixel_duty(self, duty):
		"""
		The proportion of the time pixels are lit during their time for display. Can
		be used to add clean divisions between pixels.
		"""
		assert 0.0 < duty <= 1.0 \
		     , "Duty must be between 0 and 1."
		
		# Convert to fixed point
		raw_duty = int(duty*(1<<8))
		
		# Truncate (as required) and write back
		self._cmd_reg_write(self.REG_PIXEL_DUTY, raw_duty & 0xFFFF)
	
	
	@property
	def buffer_size(self):
		"""
		Read only. Returns a tuple (size, free_spaces) representing the current size
		and state of the display buffer.
		"""
		response = self._cmd_reg_read(self.REG_BUFFER_SIZE)
		return (response>>8, response&0xFF)
	
	
	PROTOCOL_VERSION = 0x1
	
	################################################################################
	# Command Opcodes
	################################################################################
	
	# Defines the commands which can be sent to the controller. The bottom four
	# bits of a command are treated as an immediate argument to the command.
	# No operation.
	#
	# Immediate value: Ignored
	# Arguments: None
	# Returns: Nothing
	OPCODE_NO_OPERATION = 0x00
	
	# Add a line of pixels to the display buffer.
	#
	# Immediate value: Ignored
	# Arguments: The pixel values as string of bytes in big endian byte order.
	#            There should be exactly the same number of bytes as specified in
	#            the REG_DISPLAY_HEIGHT register divided by 8.
	# Returns: Returns a byte containing the number of free spaces in the display
	#          buffer. The command will not return until there is at least one
	#          free entry in the buffer as a primitive form of flow control.
	OPCODE_PUSH_LINE = 0x10
	
	# Block until the display buffer has emptied.
	#
	# Immediate value: Ignored
	# Arguments: None
	# Returns: A byte containing an undefined value.
	OPCODE_FLUSH_BUFFER = 0x20
	
	# Empty the display buffer immediately.
	#
	# Immediate value: Ignored
	# Arguments: None
	# Returns: Nothing
	OPCODE_CLEAR_BUFFER = 0x30
	
	# Read the value of a control register.
	#
	# Immediate value: The control register address to access (see reg_t).
	# Arguments: None
	# Returns: The value contained in the register as 2 big-endian bytes (16
	#          bits).
	OPCODE_REG_READ = 0x40
	
	# Write the value of a control register.
	#
	# Immediate value: The control register address to access (see reg_t).
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

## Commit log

2014-01-28 Proof of concept Arduino+TLC5916 LED driver demo.
2014-01-29 Added initial layout for LED board.
2014-01-30 Added physical design of display cylinder components.
    [model.scad, wedge.scad]
2014-01-31 Base axel print design.
    [model.scad]
2014-01-31 Revised bearing and dowel sizes and reinforced base.
    [model.scad]
2014-01-31 Printed motor fitting.
    [model.scad]
2014-01-31 Final prototype models.
    [model.scad]
2014-01-31 Added STLs for main components.
    [base_axel.stl, base_display_grip.stl, bracket.stl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]
2014-01-31 Added front-of-board graphic.
2014-02-05 Final printed part designs.
    [double_bracket.stl, model.scad, top_display_grip.stl]
2014-02-10 Added LED holding printable parts.
    [led_grip.stl, led_holder.stl, model.scad]
2014-02-10 Initial controller code which does enough to write an error to the display.
    [controller.ino]
2014-03-02 Added junction board.
2014-03-08 Added mounting holders for electronics.
    [arduino_holder.stl, junction_board_holder.stl, model.scad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]
2014-03-19 Added "all components" view of all 3D printed parts laid out.
    [all_components.stl, model.scad]
2014-11-16 Fix for Arch.
    [model.scad]
2016-09-01 Add automata demo as an alternative to the error message when buffer empty.
    [controller.h, controller.ino]
